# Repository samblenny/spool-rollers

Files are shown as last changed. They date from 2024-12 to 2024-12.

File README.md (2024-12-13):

<!-- SPDX-License-Identifier: CC-BY-SA-4.0 -->
<!-- SPDX-FileCopyrightText: Copyright 2024 Sam Blenny -->
# Spool Rollers

This repo documents my project to make 3D printable spool rollers to fit in
plastic cereal boxes. I wanted to make a filament dry box so I could feed
filament without having to unseal the box.

This didn't work out like I'd hoped because the plastic box was a little bit
too narrow to accomodate the bearings without them rubbing against the box's
side walls. But, it was a good project for learning to use OpenSCAD. Also, I
made some models for calibrating XY hole/contour compensation and bearing
press fit post diameter which may be useful elsewhere.

This is what a finished spool roller looks like:

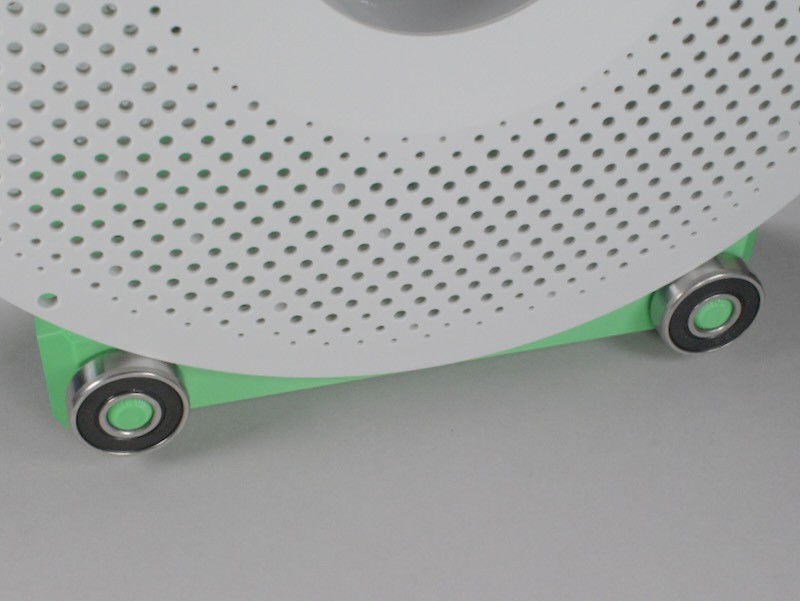
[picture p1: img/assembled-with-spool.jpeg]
fully assembled spool roller with spool


## Additional Photos

1. These are my press fit and XY compensation calibration blocks:

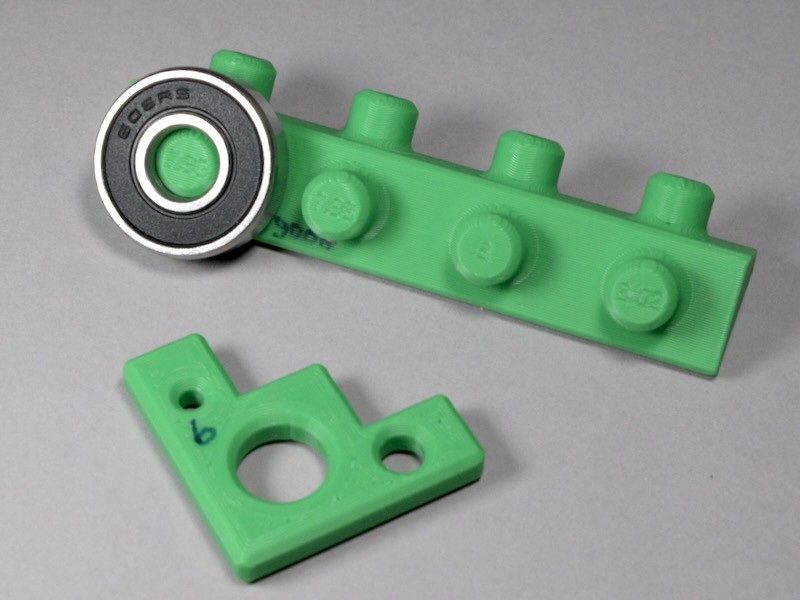
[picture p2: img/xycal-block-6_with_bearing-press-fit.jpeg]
XY compensation and bearing press fit calibration blocks
    

2. These are the two halves of the spool roller frame. The fins and slots are
   designed with 0.1mm clearance. So, with well calibrated extrusion flow and
   XY compensation, the two halves of the frame press fit with light pressure.
   The zip ties hold everything in place securely. Printing the frame halves at
   a 45° angle makes the bearing posts strong without requiring supports that
   might mess up the bearing press fit tolerance.

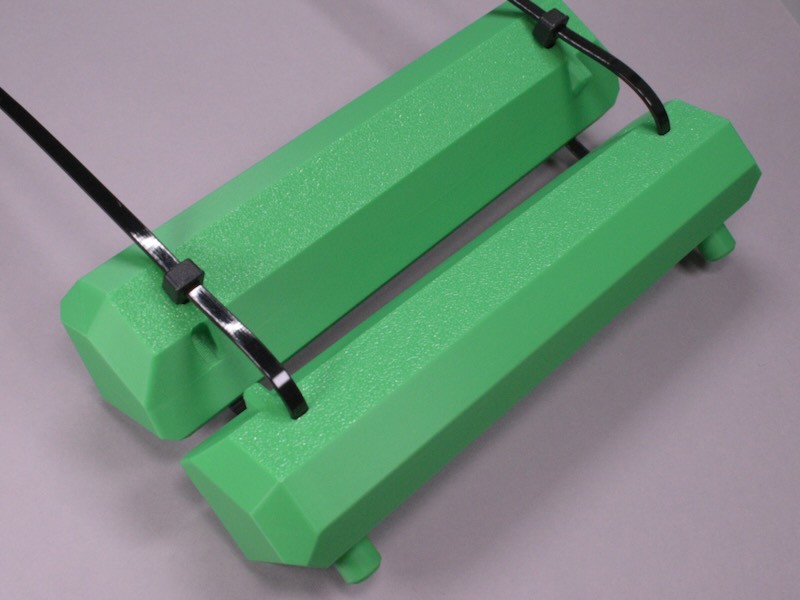
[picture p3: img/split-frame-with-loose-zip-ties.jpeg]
two halves of spool roller with zip ties
    

3. This is the fully assembled spool roller with 608-2RS press fit bearings.

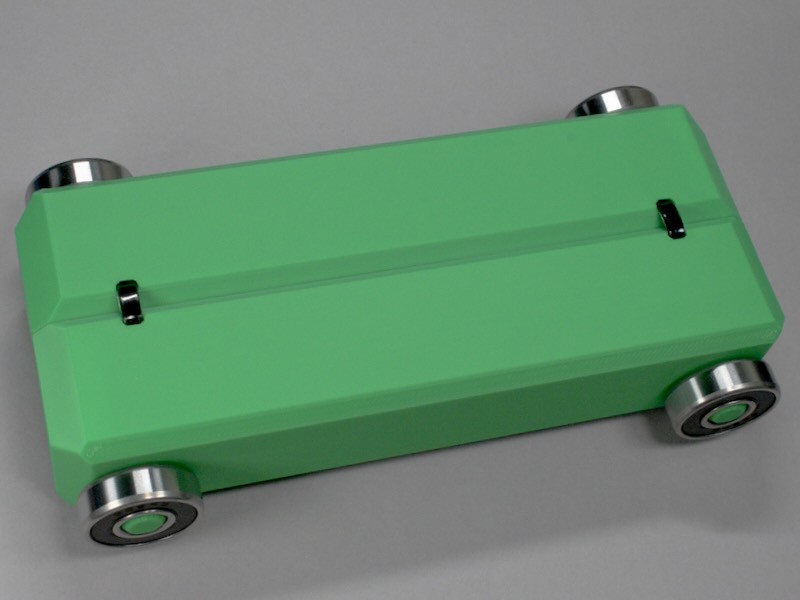
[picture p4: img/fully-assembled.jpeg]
assembled spool roller with bearings
    

4. Here, the spool roller is inside the air-tight plastic cereal box with a
   spool of filament. The bearings are jammed against the side of the cereal
   box, so the spool doesn't roll properly.

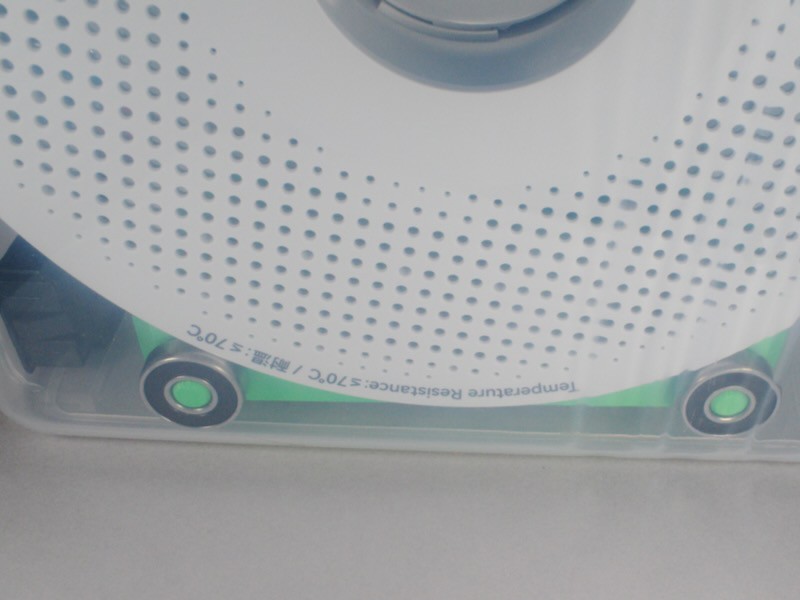
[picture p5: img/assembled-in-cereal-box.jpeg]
filament spool roller in a plastic cereal box


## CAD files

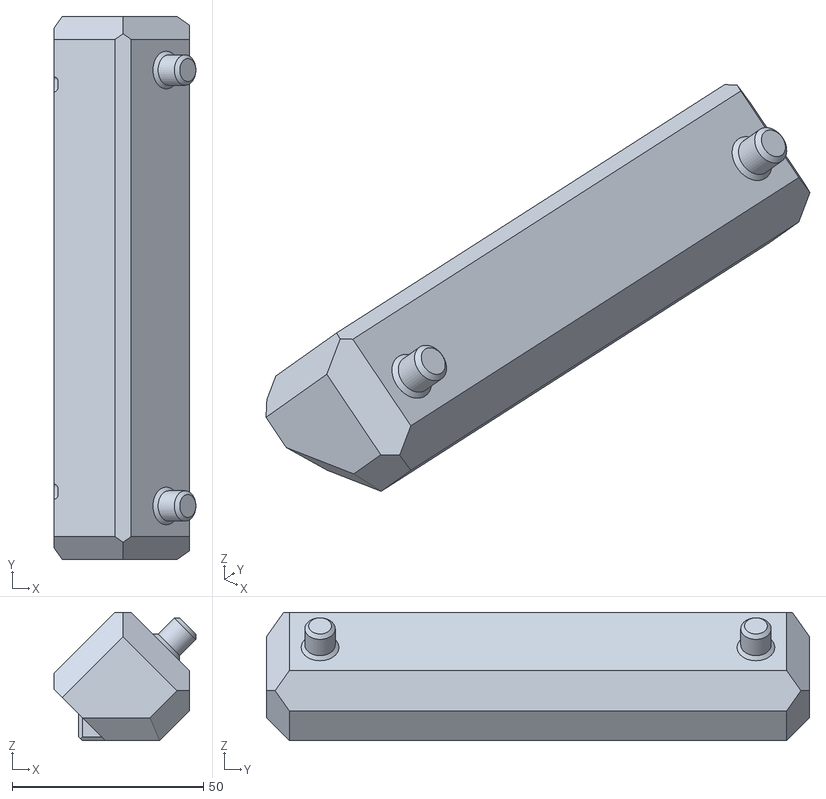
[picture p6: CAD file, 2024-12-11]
spool-roller-frame.stl
37.1 x 142.0 x 33.6

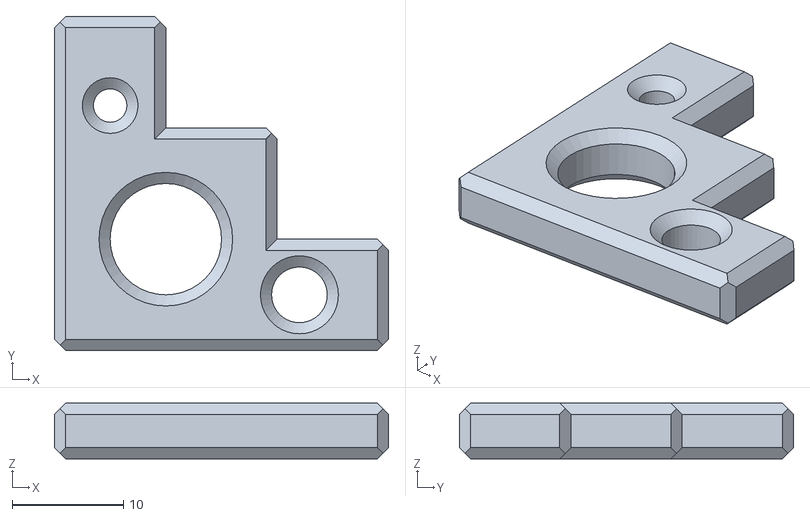
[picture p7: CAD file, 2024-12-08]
xy-calibration-block.stl
30.0 x 30.0 x 5.00

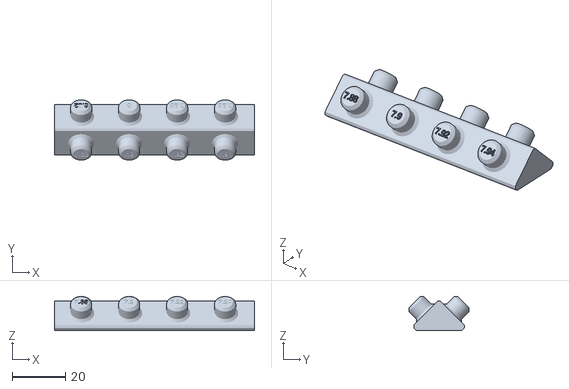
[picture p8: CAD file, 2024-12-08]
press-fit-tester.stl
75.0 x 22.6 x 12.8

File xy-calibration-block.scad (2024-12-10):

// SPDX-License-Identifier: CC-BY-SA-4.0
// SPDX-FileCopyrightText: Copyright 2024 Sam Blenny
//
// This is a test block to calibrate X-Y hole/contour compensation.

height = 5;

module stairstep_block() {
    linear_extrude(height,convexity=10)
    union() {
        square([10,30]);
        square([20,20]);
        square([30,10]);
    }
}

// This makes a tool shape to cut a horizontal chamfer
module chamfer(length=32) {
    translate([-1,0,0])
    rotate([0,90,0])
    linear_extrude(length)
    polygon([[-1,0],[0,1],[1,0],[0,-1]]);
}

// This makes a tool shape to cut a vertical chamfer
module v_chamfer() {
    translate([0,0,-1])
    linear_extrude(height+2)
    polygon([[-1,0],[0,1],[1,0],[0,-1]]);
}

// These cut the sharp squares in the inside corners
module inside_corner_wedges(height) {
    union() {
        translate([2,2,height+1]) rotate([180,0,270])  // top face
            linear_extrude(2,scale=0.5) square(4);
        translate([2,2,-1]) rotate([0,0,180])          // bottom face
            linear_extrude(2,scale=0.5) square(4);
    }
}

// This makes a chamfer path tracing the outline of the block
module chamfer_path() {
    chamfer();
    rotate([0,0,90]) chamfer();
    translate([0,30,0]) chamfer(12);
    translate([11,20,0]) chamfer(11);
    translate([21,10,0]) chamfer(11);
    translate([30,0,0]) rotate([0,0,90]) chamfer(12);
    translate([20,11,0]) rotate([0,0,90]) chamfer(11);
    translate([10,21,0]) rotate([0,0,90]) chamfer(11);
}

// This makes a tool shape to cut a hole with chamfered edges
module hole(height, diameter) {
    h = height;
    r = diameter / 2;
    rotate_extrude($fn=40)
    polygon([
        [0, -1], [r+2, -1], [r, 1], [r, h-1], [r+2, h+1], [0, h+1] 
    ]);
}

// This makes a stairstep shaped block having surfaces to measure 10,
// 20, and 30 mm distances in the X and Y directions, plus 3, 5, and
// 10 mm holes. This is meant to help set XY Contour Compensation and
// X-Y Hole Compensation calibration values in Bambu Studio, Cura, or
// other similar slicer software.
//
// To have OpenSCAD's preview mode show the shapes used to make the
// chamfer cuts, you can put a '#' or a '%' character at the start of
// the line for a cut. For example, you chould change `v_chamfer();`
// to `#v_chamfer();`
//
difference() {
    // Start with a block that has sharp corners
    stairstep_block();
    // Make chamfer cuts...
    // cut around the top and bottom perimeters
    translate([0,0,height]) chamfer_path();
    chamfer_path();
    // cut off the vertical outside corners
    v_chamfer();
    translate([30, 0,0]) v_chamfer();
    translate([30,10,0]) v_chamfer();
    translate([20,20,0]) v_chamfer();
    translate([10,30,0]) v_chamfer();
    translate([ 0,30,0]) v_chamfer();
    // remove sharp points at top and bottom of inside corners
    translate([20,10,0]) inside_corner_wedges(height);
    translate([10,20,0]) inside_corner_wedges(height);
    // cut chamfered holes
    translate([10, 10, 0]) hole(height, diameter=10);
    translate([22, 5, 0]) hole(height, diameter=5);
    translate([5, 22, 0]) hole(height, diameter=3);
}

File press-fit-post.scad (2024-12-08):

// SPDX-License-Identifier: CC-BY-SA-4.0
// SPDX-FileCopyrightText: Copyright 2024 Sam Blenny

module press_fit_post(diameter, height, chamfer=1, label=false, $fn=30) {
    r = diameter / 2;
    h = height;
    c = chamfer;
    difference() {
        // Rotate this 2D polygon around the Z axis to make a post
        // with inward chamfer at top and outward chamfer around base
        // ---,
        //    |
        //    |
        // ____\
        rotate_extrude(convexity=10)
            polygon([
                [0,0], [r+c, 0], [r, c],
                [r, h-c], [r-c, h], [0, h],
            ]);
        // Optionally inset text with diameter label on the top face
        if (label) {
            translate([-0.12,0,h-0.22])
                linear_extrude(0.3)
                    text(
                        text=str(diameter),
                        size=2.2,
                        font="Liberation Sans:style=Bold",
                        halign="center",
                        valign="center",
                        spacing=0.9
                    );
        }
    }
}

// Example post
press_fit_post(diameter=8.08, height=9, chamfer=1, label=true);

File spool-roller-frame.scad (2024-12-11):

// SPDX-License-Identifier: CC-BY-SA-4.0
// SPDX-FileCopyrightText: Copyright 2024 Sam Blenny
use <press-fit-post.scad>

// This is a 4-bearing spool roller frame that's split into two pieces.
// Printing the two halves at a 45° angle will make the press fit posts
// for the bearings resist shearing under load. This is designed to
// hinge together then fasten securely in place with two zip ties.
//
// Target Dimensions:
// - Absolute max width:        73 mm  (bottom of dry box)
// - Spool outside width:       67 mm
// - Spool inside width:        59 mm
// - Rim to filament clearance: 13 mm
// - 608 bearing thickness:      7 mm
// - 608 bearing diameter (OD): 22 mm
// - Press fit post diameter:    7.97 mm  (see press-fit-tester.scad)
// - zip tie width:              5 mm
// - zip tie thickness:          1 mm

frame_x = 57;
bearing_d = 22;
bearing_r = bearing_d / 2;
axle_d = 7.97;
axle_h = (73 - 57) / 2;
axle_2_axle_y = 114;
axle_z = bearing_r + 5;
frame_z = axle_z + bearing_r + 5;
frame_y = axle_2_axle_y + (2 * (bearing_r + 3));
zip_w = 4;
zip_h = 2;

chamfer = 3;      // normal chamfer
big_chamfer = 10; // chamfer that goes against the build plate

locator_size = 7;
locator_clearance = 0.1;

// Configure OpenSCAD's curve triangulation granularity
if($preview) {$fn=20;} else {$fn=40;}

// Log these values to the console
echo("axle center height", axle_z);
echo("frame height (z)", frame_z);
echo("frame depth (y)", frame_y);
echo("axle length", axle_h);

// Make the basic extruded cross-section shape of half the roller frame
module half_frame_step1() {
    w = frame_x / 2;
    h = frame_z;
    bpc = big_chamfer;  // chamfer that goes on the build plate
    c = chamfer;        // regular chamfer
    rotate([90,0,0])
    linear_extrude(frame_y, center=true, convexity=10)
    polygon([
        [0,bpc],[bpc,0],[w-2.5*c,0],[w,2.5*c],[w,h-c],[w-c,h],[c,h],[0,h-c]
    ]);
}

// Make a tool shape to cut zip tie holes
module zip_tie_cut() {
    w = zip_w;
    h = zip_h;
    r = (frame_z / 2) * 1.1;  // radius of the zip tie channel
    translate([-r/2.1,0,r+1])
    rotate([90,55,0])
    rotate_extrude(angle=120, convexity=10, $fn=20)
    translate([r,-h/2,0]) //-w/2,])
    hull() {
        circle(d=2);
        translate([0,h,0]) circle(d=2);
    }
}

// Add bearing press fit posts to the half frame
module half_frame_step2() {
    post_x = (frame_x / 2) - 0.05;
    post_y0 = axle_2_axle_y / 2;
    post_y1 = - post_y0;
    union() {
        half_frame_step1();
        translate([post_x,post_y0,axle_z])
            rotate([0,90,0])
                press_fit_post(diameter=axle_d, height=axle_h, $fn=40);
        translate([post_x,post_y1,axle_z])
            rotate([0,90,0])
                press_fit_post(diameter=axle_d, height=axle_h, $fn=40);
    }
}

// This makes a tool shape to cut a horizontal chamfer
module h_chamfer(length, c=1) {
    translate([- 1.5 * c,0,0])
    rotate([0,90,0])
    linear_extrude(length + 2 * c)
    polygon([[-c,0],[0,c],[c,0],[0,-c]]);
}

// This makes a tool shape to cut a vertical chamfer
module v_chamfer(height, c=1) {
    translate([0,0,-c])
    linear_extrude(height+2*c)
    polygon([[-c,0],[0,c],[c,0],[0,-c]]);
}

module end_chamfer() {
    w = frame_x / 2;
    end_y = frame_y / 2;
    zip_y = end_y * 0.7;
    bpc = big_chamfer;   // chamfer that goes on the build plate
    c = 2*chamfer;         // regular chamfer
    union() {
        h_chamfer(w, c);
        translate([0,0,bpc]) rotate([0,45,0]) h_chamfer(w, c);
        translate([0,0,frame_z]) h_chamfer(w, c);
        translate([w,0,0]) v_chamfer(frame_z, c);
    }
}

// Locator, male side
module locator_m() {
    s = locator_size;
    w = 4;             // width
    c = 1;             // chamfer size
    diagonal = sqrt(2*s*s);
        rotate([0,-45,0])
    difference() {
        cube([s, w, s]);
        // convex chamfer cut at tip of fin
        translate([0,-1,s]) rotate([90,0,90]) h_chamfer(w+2);
        // convex fillet cut, top right
        translate([0,0,s]) rotate([0,0,0]) h_chamfer(s);
        // convex fillet cut, top left
        translate([0,w,s]) rotate([0,0,0]) h_chamfer(s);
        // convex fillet cut, bottom right
        translate([0,0,s]) rotate([0,90,0]) h_chamfer(s);
        // convex fillet cut, bottom left
        translate([0,w,s]) rotate([0,90,0]) h_chamfer(s);
    }
}

// Locator tool shape, female side
module locator_f() {
    cl = locator_clearance;     // clearance between mating parts
    s = locator_size + (2*cl);
    w = 3 + cl;                 // width
    rotate([0,0,180])
    minkowski(convexity=10, $fn=30) {
        sphere(cl);
        locator_m();
    }
}

// Add end chamfers and zip tie cuts to the half frame
module half_frame_step3() {
    w = frame_x / 2;
    end_y = frame_y / 2;
    zip_y = end_y * 0.75;
    bpc = big_chamfer;  // chamfer that goes on the build plate
    c = chamfer;        // regular chamfer
    locator_z = frame_z - ((frame_z - bpc) / 2) - c/2;
    union() {
        difference() {
            half_frame_step2();
            // Zip tie cuts
            translate([0,zip_y,0]) zip_tie_cut();
            translate([0,-zip_y,0]) zip_tie_cut();
            // Locator cut
            translate([0,-zip_y,bpc]) locator_f();
            // End chamfers
            translate([0,end_y,0]) end_chamfer();
            translate([0,-end_y,0]) end_chamfer();
        }
        // Add the locator (m)
        translate([0,zip_y,bpc]) locator_m();
    }
}

// Rotate the half frame to rest on the big chamfered edge
module half_frame_step4() {
    translate([20.56+chamfer*0.9,0,-7])
    rotate([0,-45,0])
    half_frame_step3();
}

// This is for exporting an STL file of a truncated model that only
// includes the hinge, zip tie channel, and bearing posts for one end
// of the spool holder. The point is to make it easier to do test
// prints for checking locator fit, overall width, etc.
module truncate(bypass=false) {
    if(bypass) {
        children();
    } else {
        intersection() {
            translate([-50,39,-1]) cube([100,40,50]);
            children();
        }
    }
}

// change the bypass argument to false to get a truncated model for
// locator fit testing
truncate(bypass=true) {
    // This half of the frame is for the STL file (print 2 copies of it)
    half_frame_step4();
    // This half shows what a build plate with 2 halves might look like
    if($preview) {
        #rotate([0,0,180]) half_frame_step4();
    }
}

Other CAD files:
press-fit-tester.scad

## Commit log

2024-12-07 press fit post module
    [press-fit-post.scad]
2024-12-07 first draft of press fit test fixture
    [press-fit-post.scad, press-fit-tester.scad]
2024-12-07 add 4 more posts to test fixture
    [press-fit-post.scad, press-fit-tester.scad, press-fit-tester.stl]
2024-12-07 increase diameters
    [press-fit-post.scad, press-fit-tester.scad, press-fit-tester.stl]
2024-12-08 add calibration block for XY contour
    By setting a 0.05 mm XY contour adjustment (specific to my printer,
    nozzle, filament, etc.), I got the dimensional accuracy of my test
    blocks to about +/- 0.02 mm, whereas it was previously off by about
    0.1 mm. This commit adds .scad and .stl files for an xy contour
    calibration block and adjusts the press fit test fixture diameters
    to work with a calibrated printer.
    [press-fit-post.scad, press-fit-tester.scad, press-fit-tester.stl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]
2024-12-08 add holes to calibration block
    [xy-calibration-block.scad, xy-calibration-block.stl]
2024-12-09 first draft of split spool roller frame
    Notes on printing a cut down version of one end of the stl file:
    - Hinge is too low, too long, and maybe too thin, but it did help
    somewhat with keeping the two halves aligned
    - Zip tie channels work fine, but the zip tie fastening allows kind
    of a lot of play between the two halves of the frame
    - Locator overhangs were too steep (printed messy), but they still
    fit fine. Actually, the clearance was way too loose.
    - Overall frame width is too wide by maybe 2-4 mm. The bearings
    interfere with the grip ridges molded into the plastic cereal
    box. But, the bearings do line up great with the spool rim. It
    would be fine to make the frame a little n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
    [spool-roller-frame.scad, spool-roller-frame.stl, spool-rollers.scad]
2024-12-10 add x-y test block header comment
    [xy-calibration-block.scad]
2024-12-11 second rev of roller frame
    [spool-roller-frame.scad, spool-roller-frame.stl]
2024-12-11 prep for first full print
    [spool-roller-frame.scad, spool-roller-frame.stl]
